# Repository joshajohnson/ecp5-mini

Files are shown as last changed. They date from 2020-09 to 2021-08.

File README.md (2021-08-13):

# ECP5 Mini

``` 
Status: All functions on r0.2 have been proven to work. Safe to assemble your own! 

Designed in Kicad nightly, ensure you clone --recursive.
```

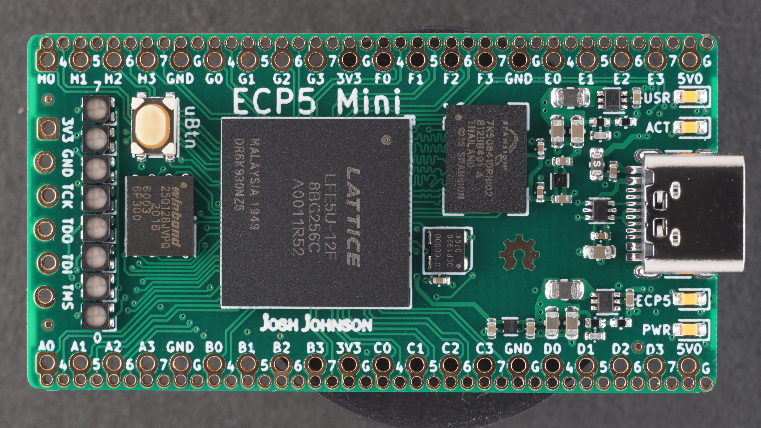
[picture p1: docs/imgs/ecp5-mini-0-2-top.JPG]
Top Side

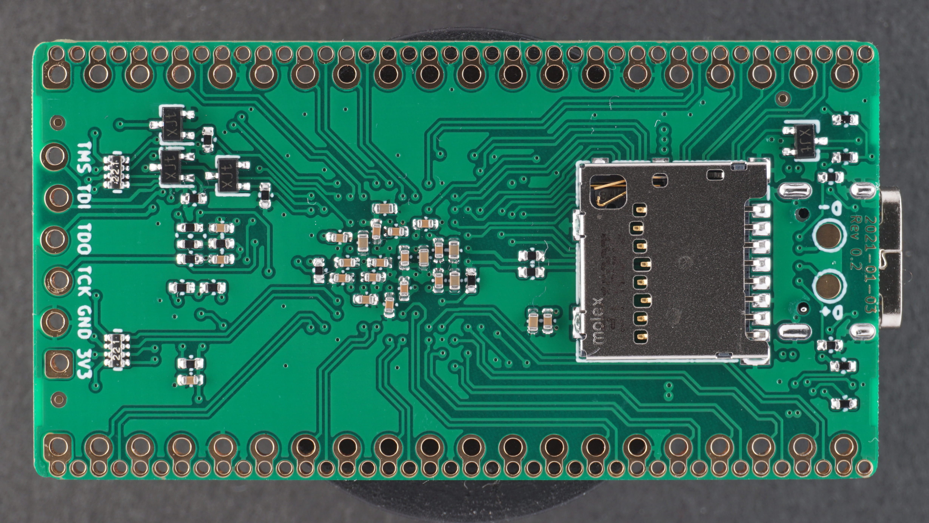
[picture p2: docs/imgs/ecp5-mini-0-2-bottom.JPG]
Bottom Side


ECP5 Mini is a Lattice ECP5 FPGA in the [Black Mesa Labs "S7 Mini" form factor](https://blackmesalabs.wordpress.com/2019/05/19/bml-s7-mini-fpga-module/).

## Key Features
- Lattice ECP5-12/25F FPGA in a caBGA256 package.
- 32 / 64 3V3 IO on 2.54mm / 1.27mm pitch grid.
- 64 Mbit HyperRAM DRAM.
- USB Full Speed (12Mbit) connection to FPGA over Type-C connector.
- MicroSD card support.
- 8 Multiplexed RGB LEDs.

## Revision History

r0.1 is depreciated. ~~hardware has been assembled with no major issues being found at time of writing. Requires more validation, particularly the HyperRAM, microSD, and signal integrity of IO.~~

r0.2 moves to 1v8 HyperRAM along with major IO changes to improve performance. Pinout is not compatiable with r0.1, but mechanically is identical. Projects utiliting the features of the board to be completed.

## Information

USB [dfu bootloader](https://github.com/joshajohnson/had2019-playground/tree/ecp5-mini) courtesy of [tnt](https://github.com/smunaut/) is working.

Example gateware can be found [here](https://github.com/joshajohnson/ecp5-mini-projects), however please note I built this board to force myself to write more HDL so it's probably full of bad practices.

Check the [issues](https://github.com/joshajohnson/ecp5-mini/issues) for any errata / improvements to the design.

## Thanks
Not only was this project inspired by the growing number of OSHW FPGA designs, but I referenced a number of them during the hardware development. A huge thank you needs to be given to these people as otherwise my design would likely have even more bugs...
- Black Mesa Lab's [S7 Mini](https://blackmesalabs.wordpress.com/2019/05/19/bml-s7-mini-fpga-module/) for the form factor and feature set inspiration.
- Greg Davil and his [OrangeCrab](https://github.com/gregdavill/OrangeCrab) and [Butterstick](https://github.com/gregdavill/butterstick) development boards. 
- Matt Venn's [Basic ECP5](https://github.com/mattvenn/basic-ecp5-pcb) design.
- SpriteTM / Hackaday's [2019 Supercon Badge](https://github.com/Spritetm/hadbadge2019_pcb).
- Luke Valenty's [TinyFPGA-EX](https://github.com/tinyfpga/TinyFPGA-EX).
- 1BitSquared's [HyperRAM PMOD](https://1bitsquared.com/collections/fpga/products/pmod-hyperram) for symbol and footprint.
- ECP5 Symbol from xesscorp's [Kicad Schematic Symbol Library](https://github.com/xesscorp/KiCad-Schematic-Symbol-Libraries).

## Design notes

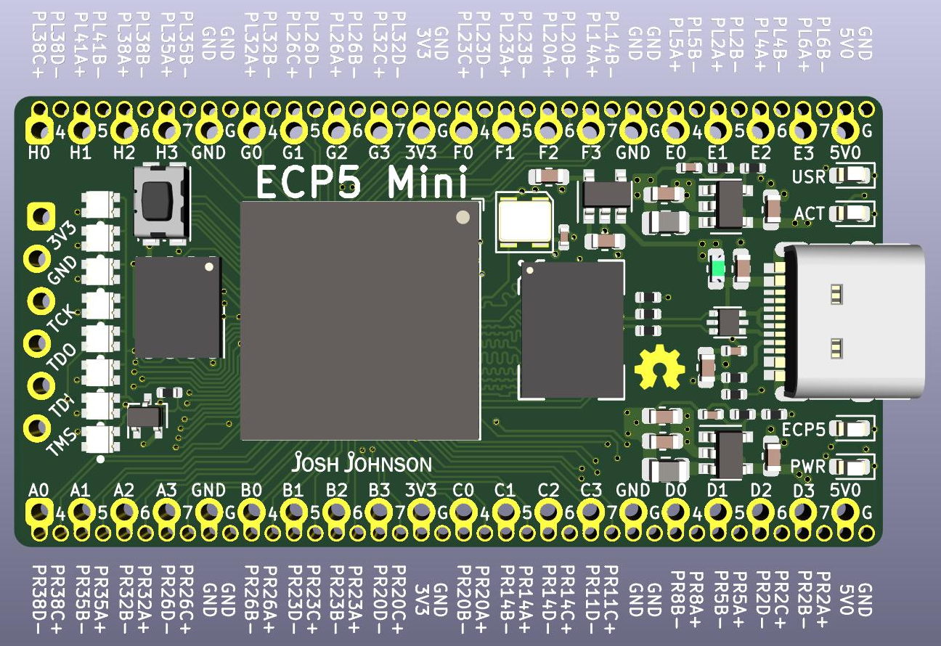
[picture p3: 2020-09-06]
docs/imgs/front-render.jpg

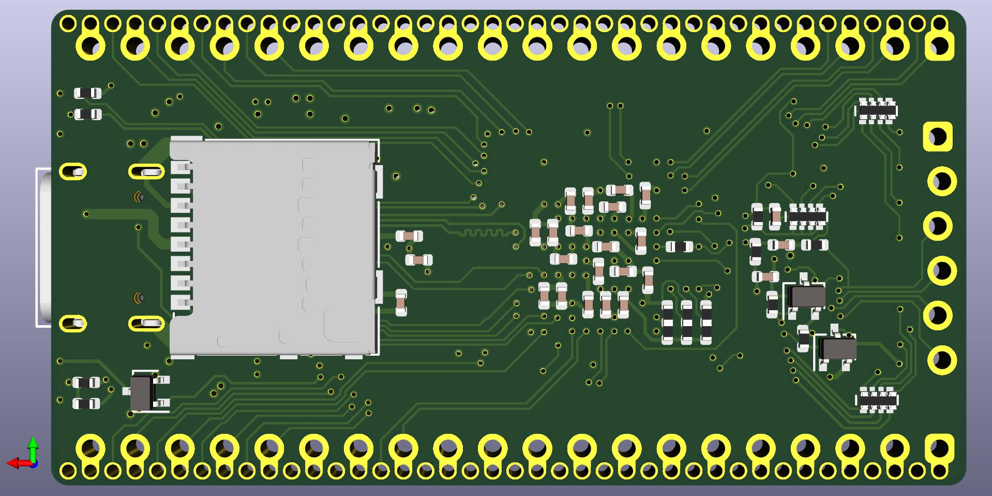
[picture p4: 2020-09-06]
docs/imgs/back-render.jpg

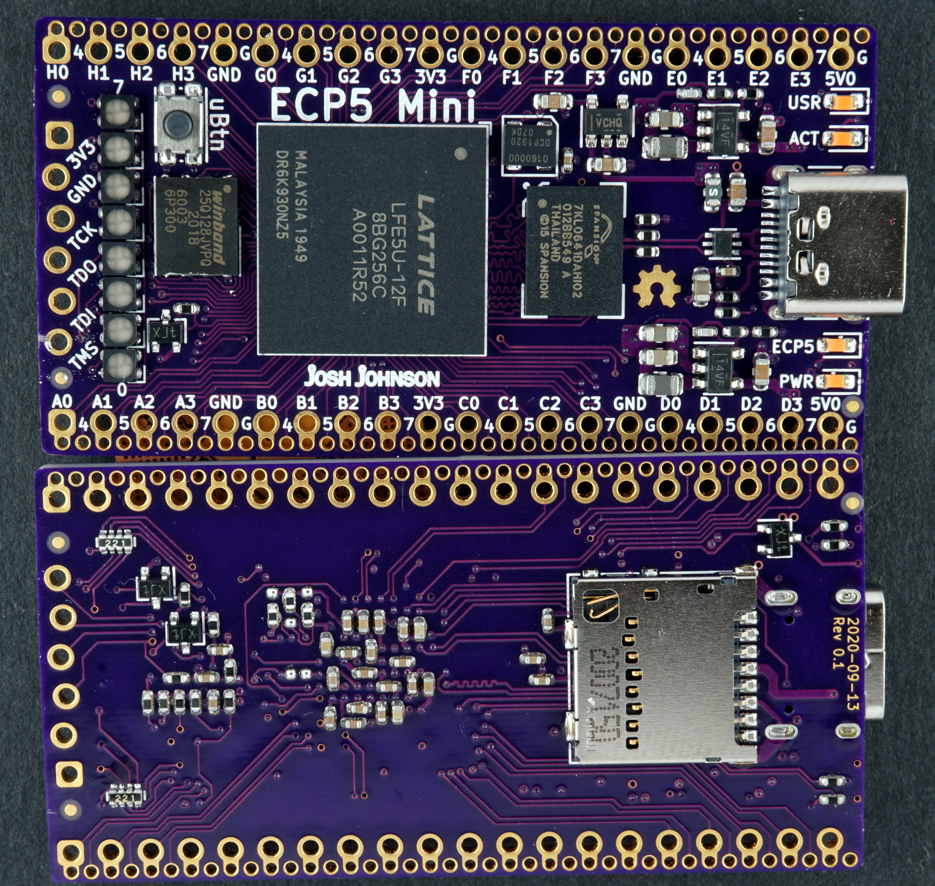
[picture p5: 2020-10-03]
docs/imgs/freshly-baked.jpeg

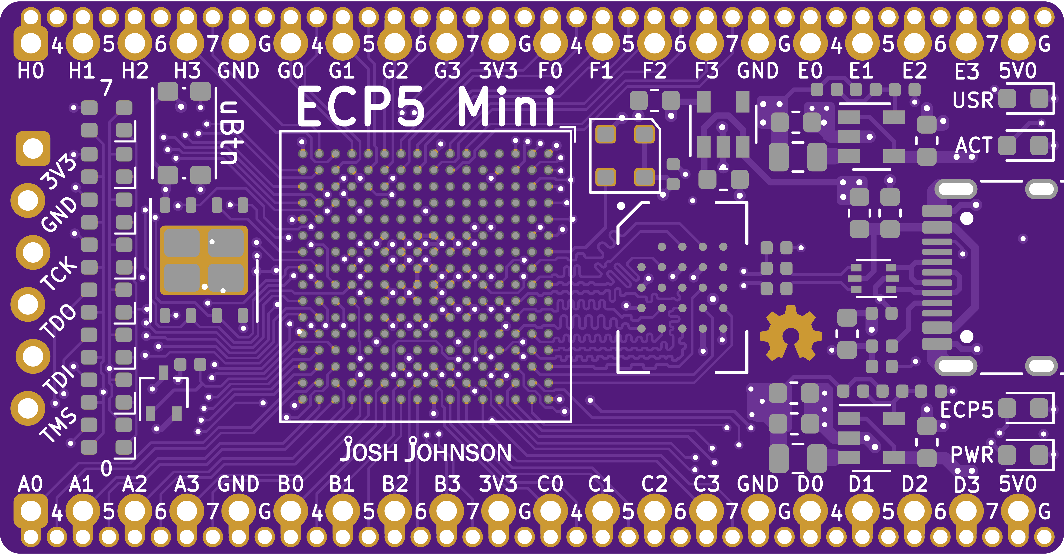
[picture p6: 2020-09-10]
docs/tracespace-render/top.png

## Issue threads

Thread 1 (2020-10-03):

r0.1 errata

joshajohnson, 2020-10-03:
This issue will document any errata / areas for improvement for future versions.

Note: HyperRAM and SD card are yet to be validated, issues list may grow once they are brought up.

Errata:
- [X] ECP5 ball T12 has a GND via partially occluding the pad
- [X] JTAG labels cannot be seen if header is installed
- [X] Diff pairs laid out uniquely, +/- is flipped compared other boards + uses C/D pair which lack differential pair drivers.
       0:4 (PMOD 1:7) = A:B etc is ideal, C:D okay as backup.

Improvements:
- [X] Move HyperRAM to 1v8 for increased speed, will require a dedicated bank / power supply
- [X] BOM optimisation / consolidation, particularly with caps and voltage feedback network
    - [X] Move usb_pu to bottom side with rest of 1k5 resistors
    - [X] 1v1 regulator appears to work fine with 2 x 10uF caps, does not require 22uF
    - [X] USB input cap can be commonised
    - [X] LED resistors to 1k5 - reduces BOM along with being a better brightness
    - [X] Standardise on 0402 components where possible
    - [X] Move DC:DC to smaller SOT package
    - [X] All LED drivers to bottom of board, confirm CDONE requires FET?
- [X] Move status LED vias away from the edge to aide with panelisation
- [X] Add USB pads under USB connector for easy flashing
- [X] Move as many vias up to 0.2/ 0.50mm as possible, or 0.2/0.45 under BGA
- [X] Change button as KMR2 is a bit hard to press

TODO:
- [ ] ~~Validate HyperRAM and SD card on r0.1 before ordering r0.2.~~
- [X] Update PMOD breakout to use ports B,C,F,G.
- [X] Update DFU bootloader with latest pinout.
- [X] Update .pcf and change makefile so examples work on both boards.

joshajohnson, 2020-12-09:
Expanding on the pinout errata, there are two main areas for improvement. Please not I'm not an ECP5 expert (far from it!) so there may be some inaccuracies in the below.

#### Diff pair pinout is not compatible with the de-facto PMOD standard.

The de-facto standard for diff pairs over a PMOD connector is +/- on 1/7, 2/8 etc. [example](https://raw.githubusercontent.com/gregdavill/advent-calendar-of-circuits-2020/main/icebreaker%2B%2B/production/icebreaker%2B%2B.pdf)
Ports A -> D on the  ECP5 Mini have the diff pairs the other way around, so may cause issues.
If you are designing the ECP5 Mini into a custom board, or using single ended IO, this is not a problem.

#### C/D Pairs are used for IO on Left and Right Sides

Per the lattice [IO Guide (pages 6, 10)](https://www.latticesemi.com/-/media/LatticeSemi/Documents/ApplicationNotes/EH/FPGA-TN-02032-1-3-ECP5-ECP5G-sysIO-Usage-Guide.ashx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), there are up to two sets of diff pairs per IO block on the left and right sides of the ECP5. The A/B pair contain true LVDS drivers, whereas the C/D pair do not. If possible we should break out A/B pairs instead of C/D pairs, as they have greater functionality. Note the top / bottom sides do not have LVDS drivers on any pins, so we should aim to have dedicated PMODs with the LVDS pairs run to them, leaving other PMODSs with the   lesser featured IO. If you are not taking advantage of the LVDS drivers, this is not a problem.

giggiu16, 2020-12-30:
Hi @joshajohnson!
When do you think the rev 0.2 will be finished? I really would like to try to assemble the board, as my first BGA assembly test 😃.

Thank you for your good work!

joshajohnson, 2020-12-31:
Hey @giggiu16!

I'm hoping to finish layout in the next day or two, but I won't have time to assemble / validate the changes / update the constraints file etc for a few months (I'm not guaranteeing anything before March - April, but I'll do my best to get around to it earlier).

In saying this, all of the IO changes are low risk as they are just changing the pinouts, and aside from the hyperram moving to 1v8 there were not too many changes to the core of the board, so should be fairly low risk.

I'll ping you here once it's done so you can kick off the assembly :)

giggiu16, 2020-12-31:
Thank you @joshajohnson and thank you again for your good work. I will try my best to assemble the r0.2 and test out the other untested things :)

joshajohnson, 2021-01-04:
Hey @giggiu16, 0.2 should be ready to order, files are in `hardware/0.2/outputs`. I've just ordered mine to fingers crossed they work...

Feel free to fire away with any questions / issues / PRs etc, interested to hear how you go!

Closed 2021-01-04.

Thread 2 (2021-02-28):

r0.2 Errata

joshajohnson, 2021-02-28:
This issue will document any errata / areas for improvement for future versions.

Note, whilst the board has passed the smoke test, it has not been fully brought up so this list is subject to growing.

- [ ] USB CC pulldown resistors are in the way of the SD card, card can still be inserted but is less than ideal.
- [ ] PD37+- diff pair is not routed correctly under the SD card.
- [ ] C510 is too close to C514
- [X] C14 and R2 should have their positions swapped in layout.

giggiu16, 2021-03-01:
Hey @joshajohnson! For a very big coincidence I assembled the r0.2 simultaneously with you! 😄
Just had the time to perform (a successful!) smoke test and an initial JTAG chain scan (w/ openocd& ftdi/jlink) but no devices were discovered. Do you managed to program the ECP5?
Thank you!

joshajohnson, 2021-03-01:
Hey @giggiu16, I was able to program both of the r0.2 boards I assembled. I used [ecpprog](https://github.com/gregdavill/ecpprog) with a FT232.

Let me know how you go / if there is anything I can do to help!

giggiu16, 2021-03-01:
@joshajohnson -- thank you so much!
Just changed to FT232 + ecpprog combination and...
```
init..
IDCODE: 0x21111043 (LFE5U-12)
ECP5 Status Register: 0x06400000
flash ID: 0xEF 0x40 0x18 0x00
Bye.
```

I confirm also that the bootloader is working correclty even on r0.2:
```
Found DFU: [1d50:614b] ver=0005, devnum=2, cfg=1, intf=0, path="20-4", alt=2, name="Bootloader", serial="e46050640f354126"
Found DFU: [1d50:614b] ver=0005, devnum=2, cfg=1, intf=0, path="20-4", alt=1, name="RISC-V firmware", serial="e46050640f354126"
Found DFU: [1d50:614b] ver=0005, devnum=2, cfg=1, intf=0, path="20-4", alt=0, name="ECP5 bitstream", serial="e46050640f354126"
```

Thank you so much!

joshajohnson, 2021-03-01:
@giggiu16 Nice work! If you are in the position to share what you are using it for I'd be keen to hear, otherwise have fun!

giggiu16, 2021-03-04:
@joshajohnson for sure: no specific use case in mind for now. I'll use your board to continue learning FPGA programming, I didn't wanted to be limitated in GPIO pins too much comparing other "low-cost" solutions. I like also assemblying electronic prototypes and I used your board as first BGA assembly test 😄. Next 2 boards in queue, and one is with the 25F variant 😉.

joshajohnson, 2021-03-05:
@giggiu16 Awesome!

One thing I should say is that the 12F and the 25F are the same silicon, but with a different IDCODEs. If you use the open tools you'll be able to use all 25K LUTs on the 12F!

amitvasudevan, 2022-09-28:
Hi @joshajohnson and @giggiu16! Nice work on the ECP5-mini board. How did you solder the BGA on the PCB? Did you just use a hot air gun/flux combo or was it something more sophisticated? Thanks!

joshajohnson, 2022-09-28:
Hi @amitvasudevan, I'd suggest reflowing it along with the rest of the components. You can do it with hot air but getting even heating is a bit more challenging.

joshajohnson, 2022-09-28:
Closed on accident

amitvasudevan, 2022-09-28:
Thanks for the response @joshajohnson !

I am a newbie when it comes down to soldering so please forgive my naive questions below :)

- From what I read up on reflow seems like a three step process: (a) obtain stencil for PCB, (b) apply solder paste over stencil, and (c) place the pcb in the reflow oven. Correct?
- I am planning to order the PCB via OSHPark; do they provide stencils?
- Also I noticed that your PCB design has components soldered on both the top and bottom. How does that work in the reflow oven? Do you do one side first and then the other? If so, won't the already soldered components on the side down reflow and dislodge?
- I am planning on assembling this at home and was looking for reflow ovens on amazon and it seems like there are units available for ~$250 or so. Is there a specific unit you would recommend? Also I am guessing the temperature will depend on the solder paste being used correct?

Thanks for your time and help! Can't wait to get started...

joshajohnson, 2022-09-29:
- Correct

- OSHStencils (no relation to OSHPark) provide stencils.

- Yes, you reflow the bottom side then the top side. There is no issues with the bottom side falling off on the second time through the oven as they are all lightweight.

- Esden has a good summary of modifying an oven [here[(https://forum.1bitsquared.com/t/upgrading-a-t962a-reflow-oven/126). I have a T962 (not T962A) and it's okay, but I'd buy the higher end option next time.

- Yes you will want to play around with a few boards / temperature profiles before throwing your first actual board in there to see what works best.

amitvasudevan, 2022-09-29:
Thanks @joshajohnson! This is very helpful. I looked at the T962/A modifications and found the thermocouple interface board is no longer available from 1bitsquared. Is that an important component or can I still work without it?

joshajohnson, 2022-09-30:
You can get away without it, I don't have one in my machine.
Just make sure you add the [cold junction compensation DS18B20](https://github.com/UnifiedEngineering/T-962-improvements/wiki/Dallas-18B20-for-cold-junction-mod) in the controller board to get a bit closer with the temperature.

amitvasudevan, 2022-09-30:
Got it! Would you be willing to share details on the solder paste you used and the corresponding T962 profile that worked for you? I am planning to use lead-free solder paste (just to be less toxic) and it seems like it could work with the SAC305 lead-free paste as described [here](https://www.youtube.com/watch?v=Hkl6rzhMPHY). Thanks again for your time and help!

joshajohnson, 2022-10-01:
I use leaded T4 paste so the profile won't be too useful.
Main thing to keep an eye out for is that any fast ramp rates will cause the oven to lag as it can't keep up with the fast changes in temperature, so pick a slow profile and run it a few times to see how the oven responds.

I've had my oven for 4 years now and as long as I put a part less than 80mm x 80mm in the center of the board it will solder without too many issues, but it took a while to get to that point.

amitvasudevan, 2022-10-04:
Thanks @joshajohnson! I have placed my order for the T962 and it should get here next week. Also, I found a lead-free solder paste with Tin/Bismuth alloy from Chipquik. If you look at the datasheet [here](http://www.chipquik.com/datasheets/SMDLTLFP.pdf), it seems to have a pretty smooth reflow curve (about 1C temp rise per second). Is that a slow enough profile for the oven you think?

joshajohnson, 2022-10-06:
Ah sorry I might not have been clear - you can use any solder paste but just need to make sure the ramp rate on your oven is slow.
Mine has two options - one shaped like a triangle and another that has a long soak profile before peaking, and I use the latter as it can't match the sharp profile.

Oscilllator, 2024-11-09:
Hi,

Did anyone manage to make use of the RAM on this board? I'm doing my first ECP5 board and am looking for designs to work from. RAM is a nice-to-have for my design so it would be good to have a known good implementation to work from.

joshajohnson, 2024-11-09:
Hi Dave,

Hyperram has been confirmed to work via a memtest in Litex.

Code is here:

https://github.com/joshajohnson/ecp5-mini-projects/tree/master/litex

Thanks

-------- Original Message --------
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

CCampbell71, 2024-12-14:
@joshajohnson I'm looking at assembling on! But the 25 vs 12... you mentioned the IDCODEZ is different, will I have issues flashing and using the dfu bootloader?

joshajohnson, 2024-12-17:
Hi @CCampbell71, you can fit whatever part you want. Just make sure this part of the makefile is correct for the IC.
https://github.com/joshajohnson/ecp5-mini-projects/blob/master/verilog/common.mk#L3

CCampbell71, 2025-01-04:
Thanks @joshajohnson! Ok so I got the pcb assembled, I used your design for the FPGA portion including usb, buttons, jtag, spi etc. exactly the same. I am now unable to connect via jtag. I tried ECPPROG and open fpga loader, and am using a TIGARD (Ftdi) cable. Verified all power banks are correct and DONE pin pulls low indicating it moved into initialization. But I cannot get it to recognize the fpga via jtag. Any recommendations for the first flash? It has not been configured before

joshajohnson, 2025-01-05:
It's been so long since I flashed an ECP5 I'm struggling to remember what it looks like @CCampbell71!

Assuming you are not getting any readback of an IDCODE at all?
All I can think of is a dodgy connection between Tigard (correct pins to each spot? tight fit in holes?) or bad soldering on the BGA.
Otherwise maybe it's a driver / udev issue? Can you try a different device and see if you can find that on JTAG?

Sorry for the non answer, let me know how you go.

CCampbell71, 2025-01-05:
Yes, I've triple checked all connections and used openfogaloader/ ecpprog and native diamond software. Still cannot get id code :/. Question: when you have a fresh brand new board that's never been configured, you simply power it up and connect JTAG? I do see behavior of the DONE pin led come on and then goes off indicating the FPGA moved on to the initialization phase. But doesn't configure (obviously) also tried straight up flashing the spi chip (Winbond) and I'm getting hit with the write protection stuff. Working through that with various software/programmers as well 😄

CCampbell71, 2025-01-05:
I did notice the hardware checklist callls for 4.kohm pullups on most of the jtag pins. I didn't do this but looks like you didn't either so I figured either was a non issue. TCK is pulled down via 10kohm

joshajohnson, 2025-01-06:
Yeah I think you just connect JTAG and send it, IIRC you should always be able to get the IDCODE irrespective of the device state.
Pin strapping sounds fine to me. Sorry for not being much use.

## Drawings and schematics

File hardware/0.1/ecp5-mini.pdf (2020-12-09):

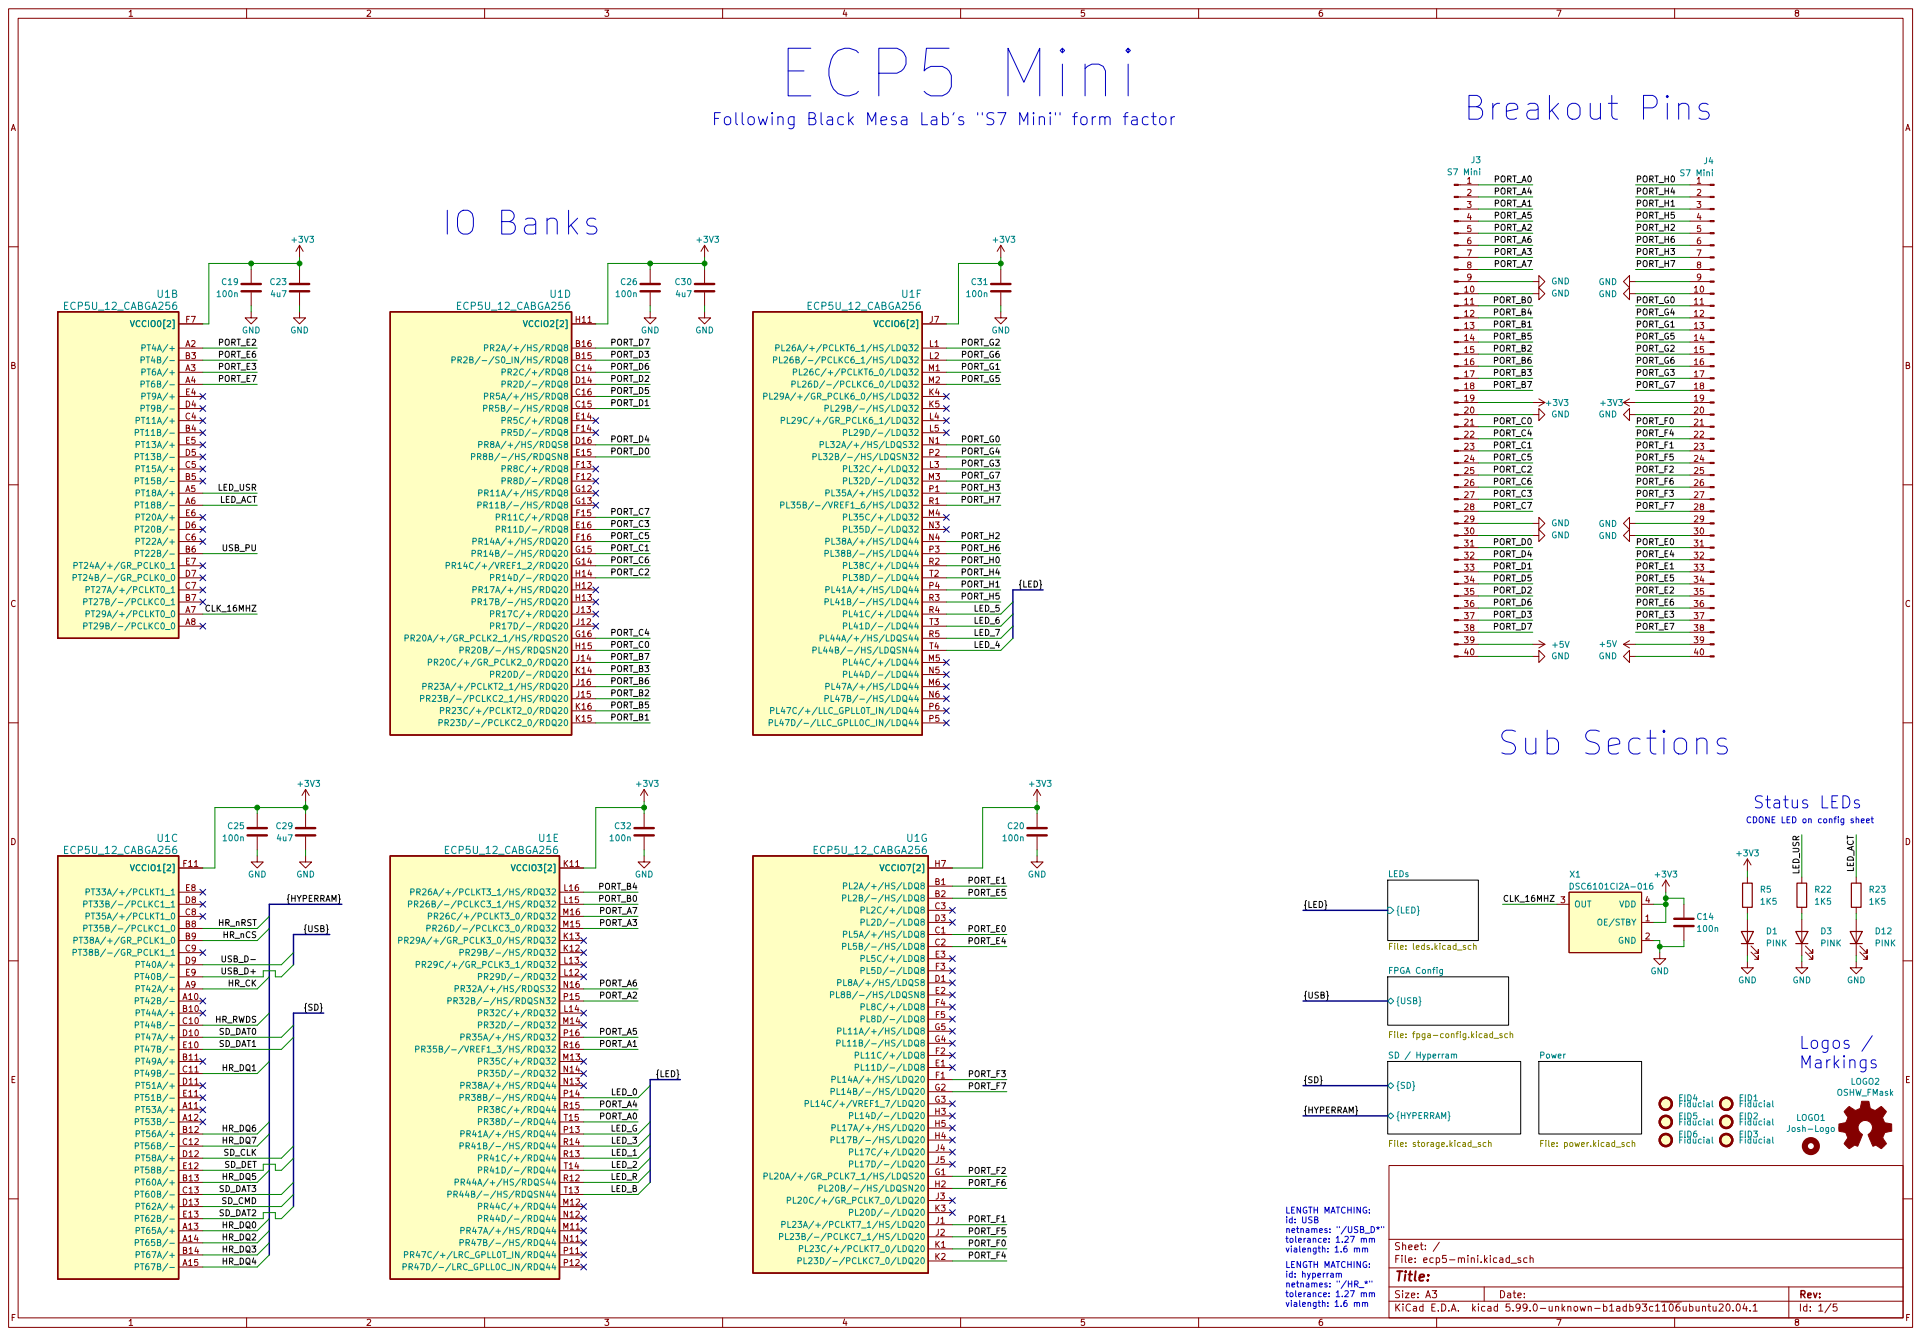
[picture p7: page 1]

Following Black Mesa Lab's "S7 Mini" form factor

Sub Sections
{HYPERRAM} LEDs File: leds.kicad_sch
{LED} LENGTH MATCHING:

CDONE LED on config sheet

File: fpga-config.kicad_sch
File: ecp5-mini.kicad_sch Sheet: / SD / Hyperram

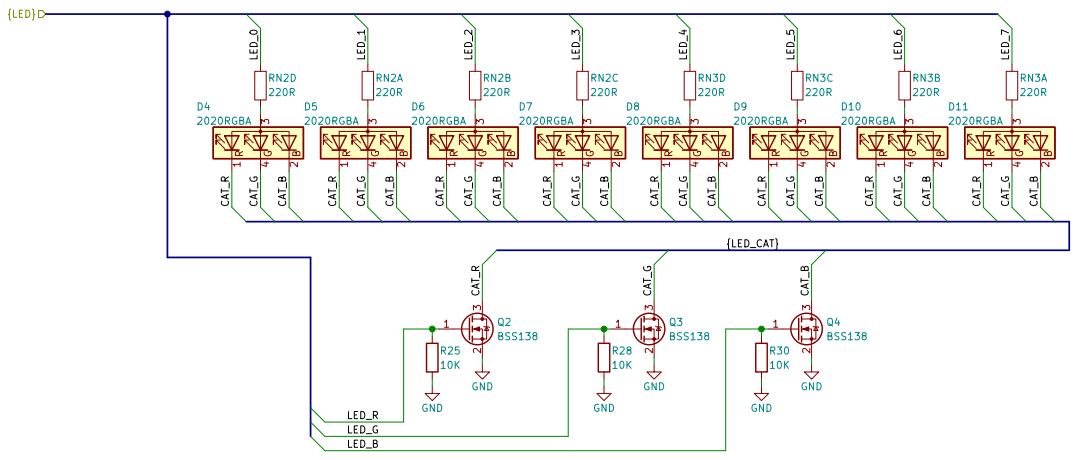
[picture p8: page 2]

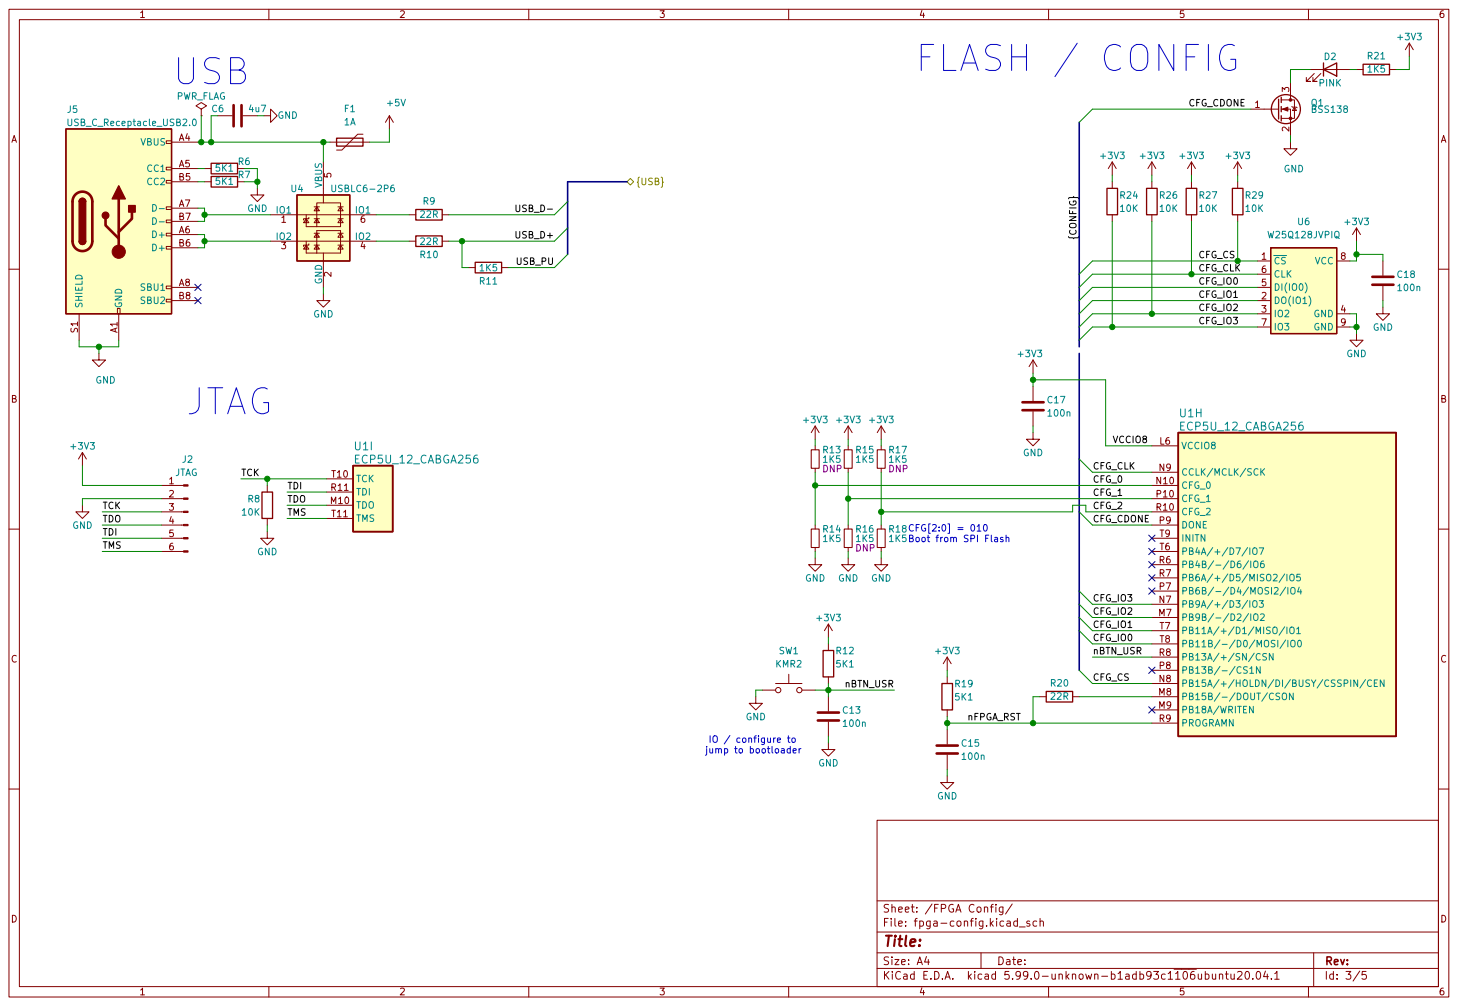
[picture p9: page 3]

CFG[2:0] = 010 Boot from SPI Flash

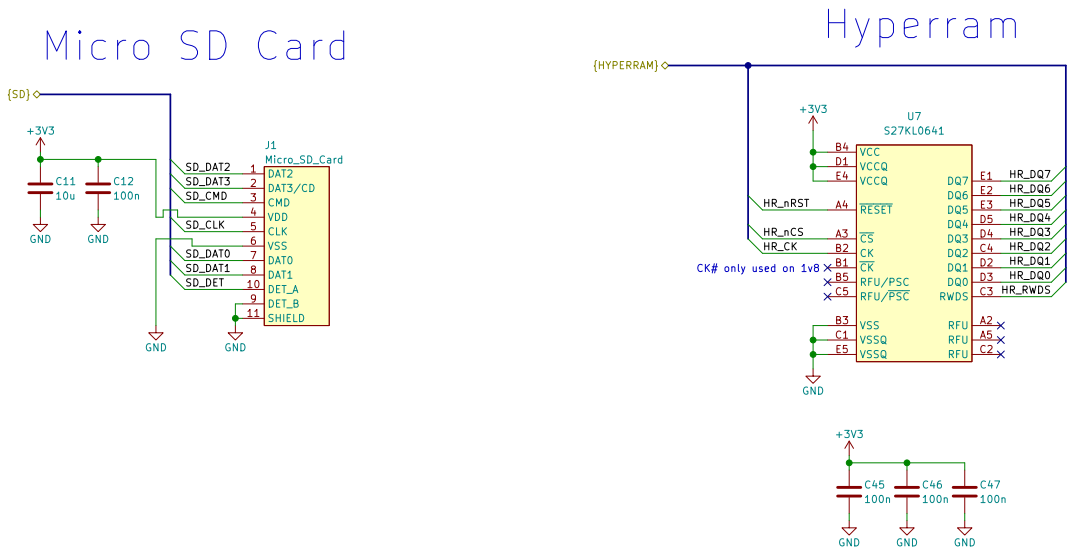
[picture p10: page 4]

CK# only used on 1v8

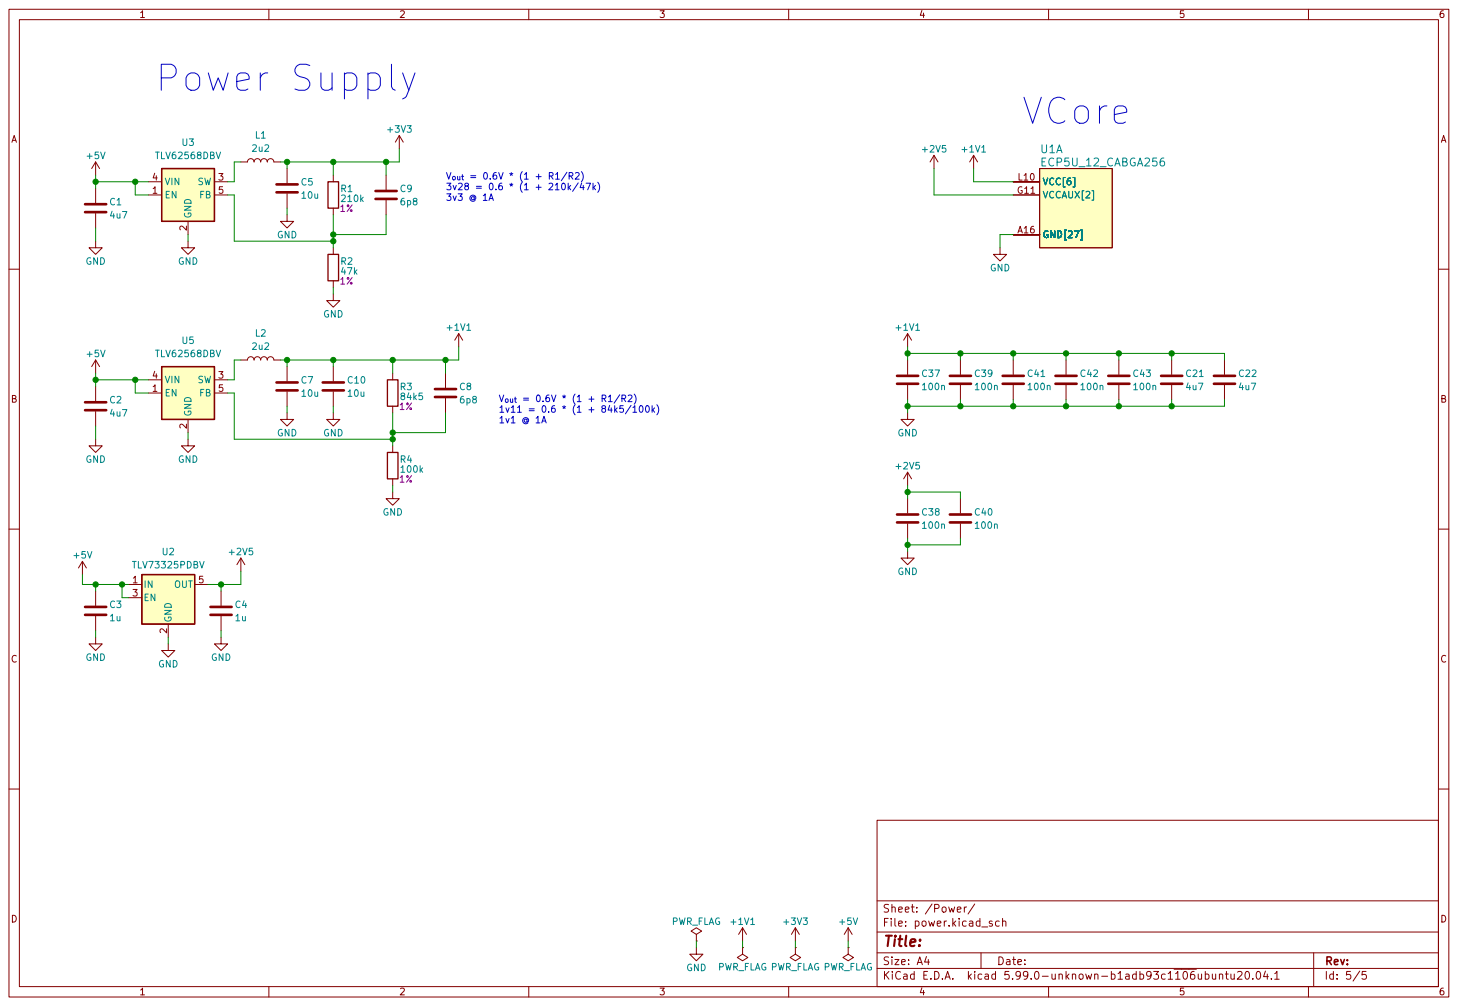
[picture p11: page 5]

File: power.kicad_sch Sheet: /Power/
Id: 5/5 Title:

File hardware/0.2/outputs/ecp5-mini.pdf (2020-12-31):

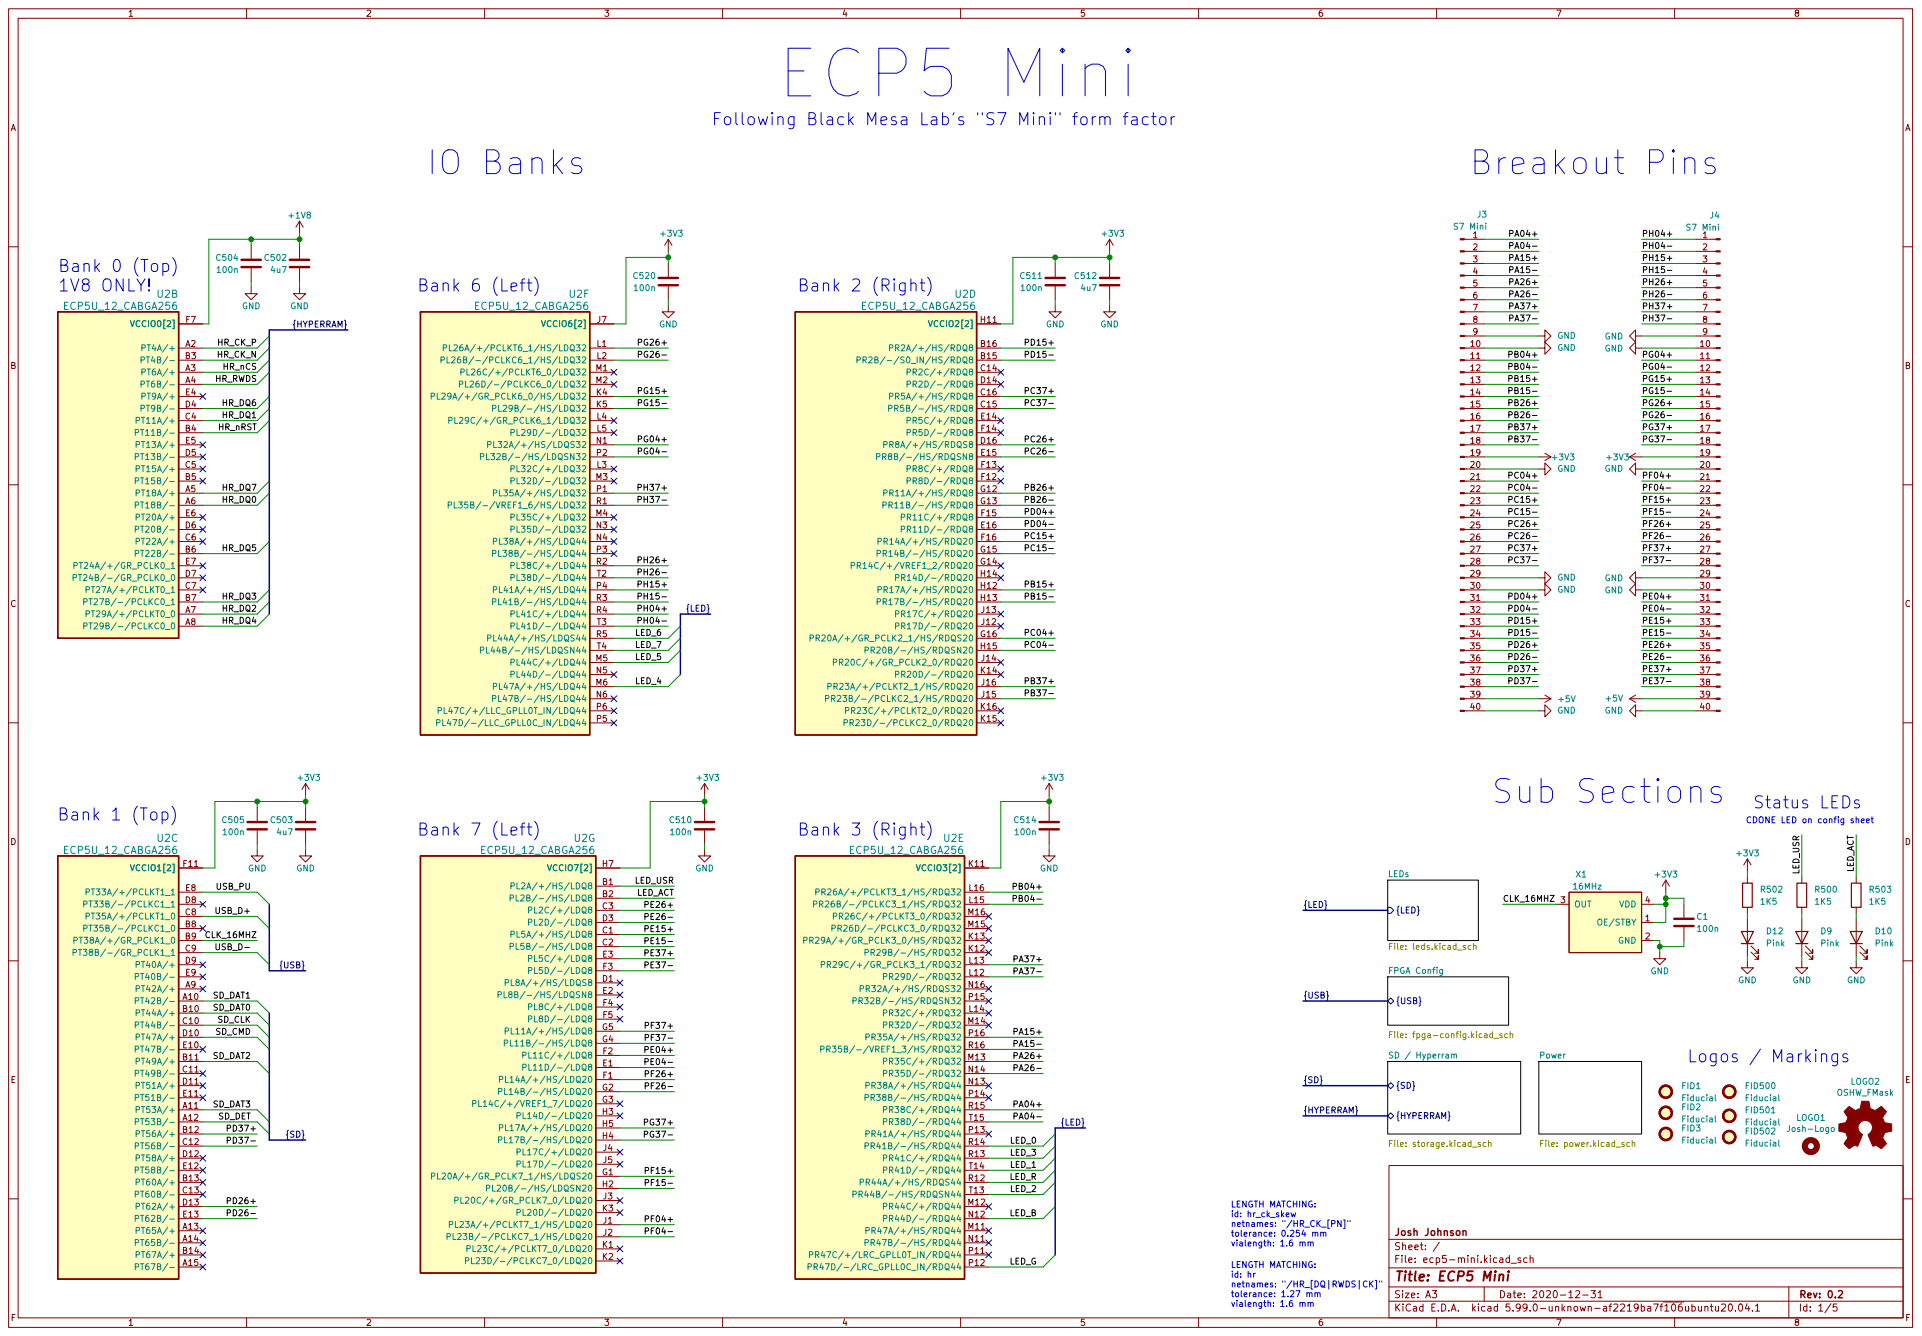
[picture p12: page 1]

Following Black Mesa Lab's "S7 Mini" form factor

D9Pink FID500 Fiducial FID502 Fiducial FID501 Fiducial FID2 Fiducial FID1 Fiducial FID3 Fiducial

File: ecp5-mini.kicad_sch Sheet: / Josh Johnson

LENGTH MATCHING:
id: hr netnames: "/HR_[DQ|RWDS|CK]"

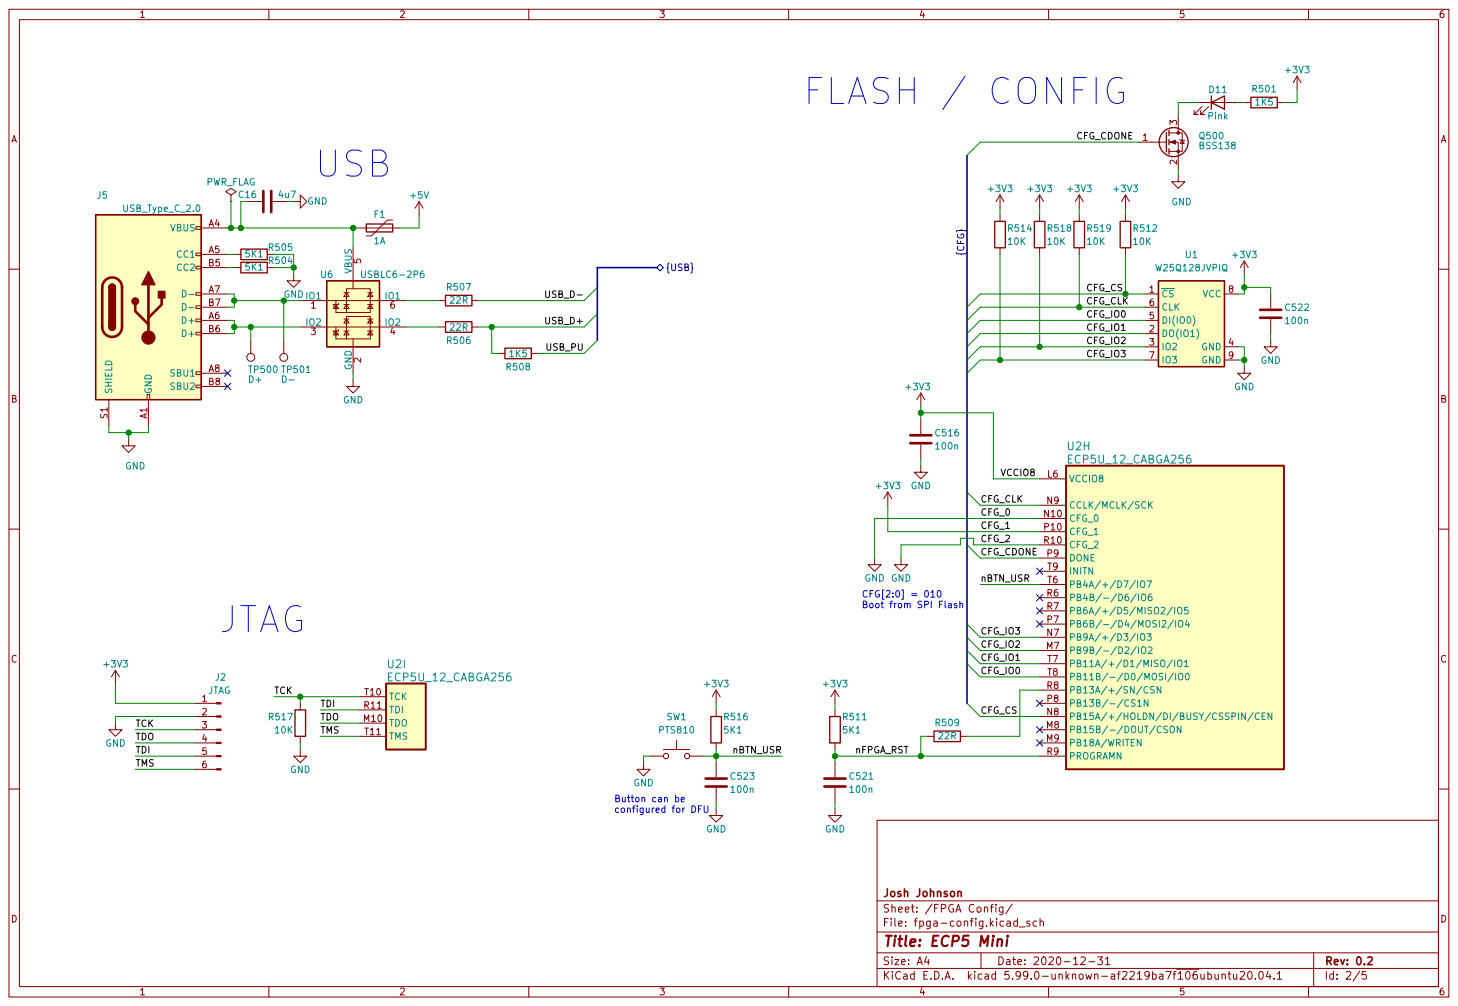
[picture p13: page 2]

Sheet: /FPGA Config/ Josh Johnson C521

Button can be configured for DFU

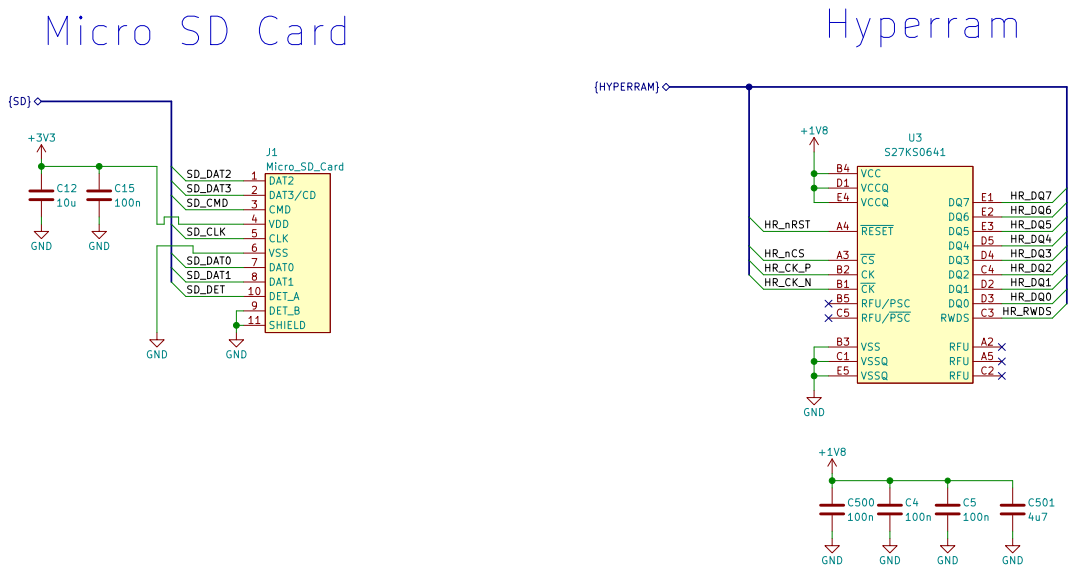
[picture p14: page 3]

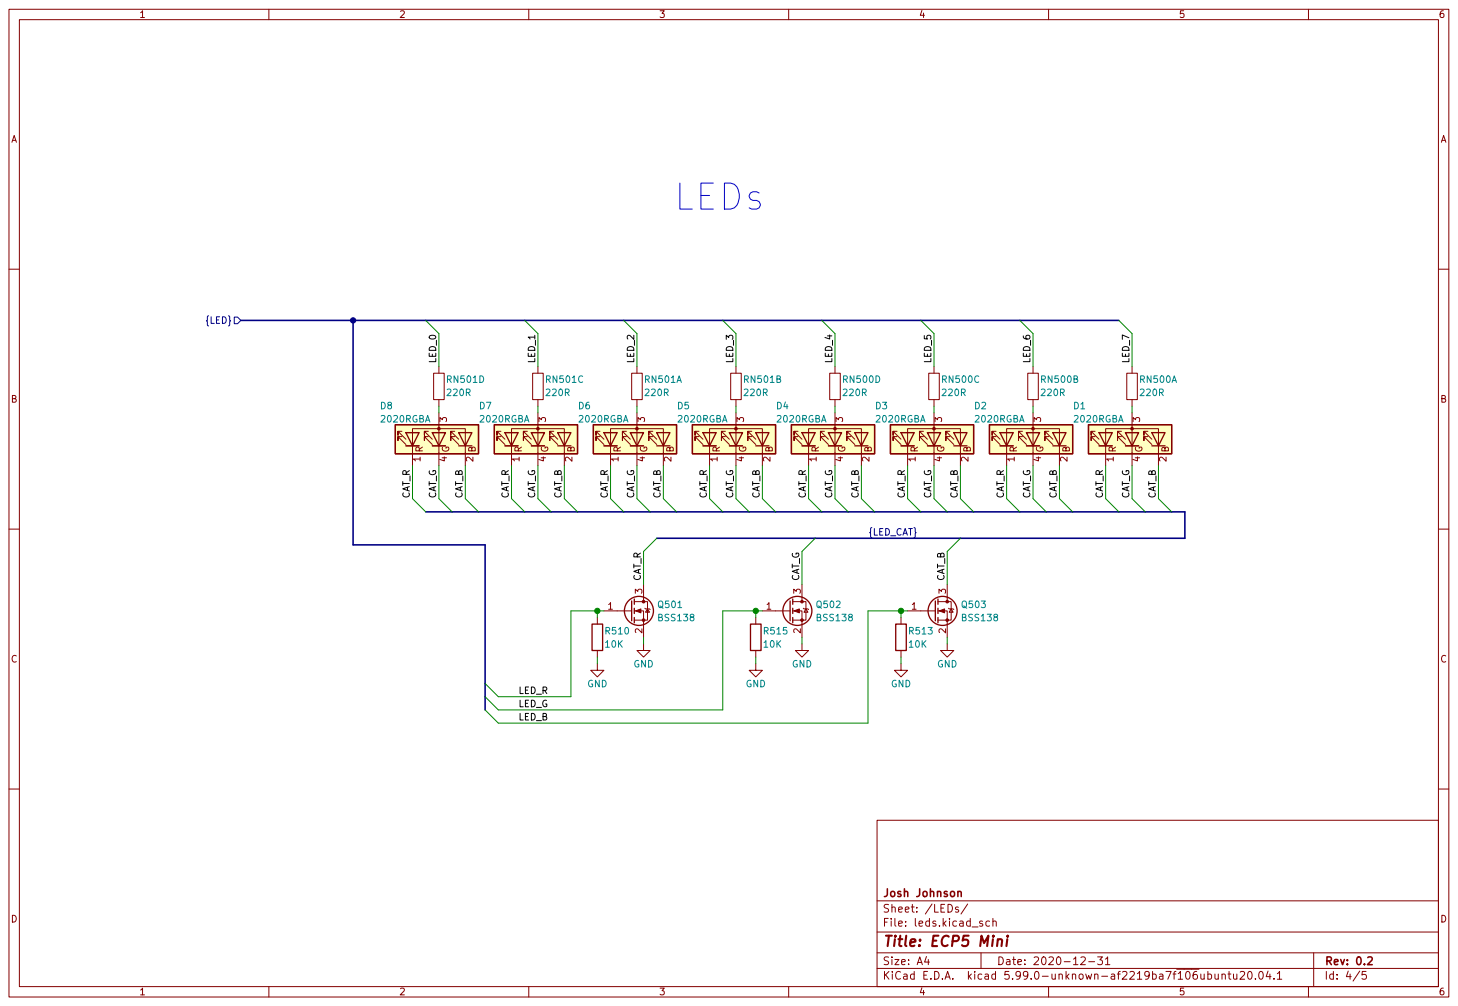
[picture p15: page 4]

File: leds.kicad_sch Sheet: /LEDs/ Josh Johnson

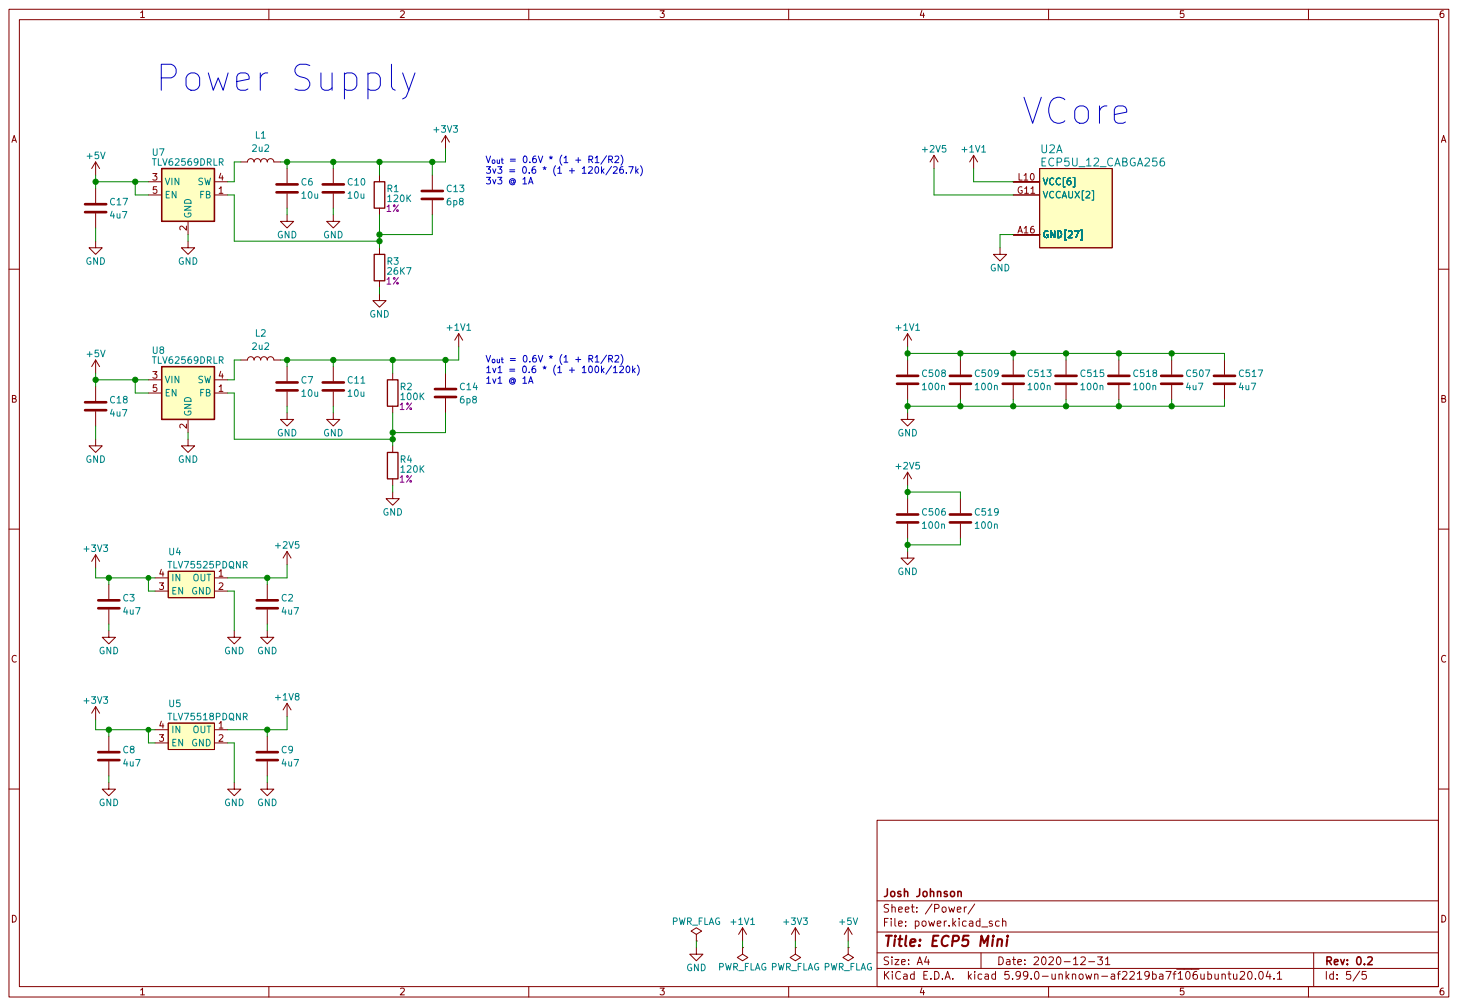
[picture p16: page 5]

2 VIN 3 SW 4 EN 5U7TLV62569DRLR GND

File: power.kicad_sch Sheet: /Power/ Josh Johnson

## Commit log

2020-08-21 set board outline
    [ecp5-mini.kicad_pcb, ecp5-mini.kicad_sch, ecp5-mini.sch]
2020-08-21 looks like it will fit
    [ecp5-io.kicad_sch, ecp5-mini.kicad_pcb, ecp5-mini.kicad_sch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]
2020-08-23 update gitignore
    [ecp5-mini.kicad_pcb, ecp5-mini.kicad_sch]
2020-08-27 power + leds + hyperram
    [board-io.kicad_sch, ecp5-mini.kicad_pcb, fpga-config.kicad_sch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]
2020-08-28 all 3d models added
    [board-io.kicad_sch, ecp5-mini.kicad_pcb, ecp5-mini.kicad_sch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]
2020-08-28 decoupling down + outer pins fanned out
    [ecp5-mini.kicad_pcb, ecp5-mini.kicad_sch, fpga-config.kicad_sch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]
2020-08-28 cleaning up schematic
    [board-io.kicad_sch, ecp5-io.kicad_sch, ecp5-mini.kicad_pcb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]
2020-08-29 layout ++
    [ecp5-mini.kicad_pcb, ecp5-mini.kicad_sch, fpga-config.kicad_sch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]
2020-08-29 hyperram routed
    [ecp5-mini.kicad_pcb, ecp5-mini.kicad_sch, fpga-config.kicad_sch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]
2020-08-29 half IO laid out
    [ecp5-mini.kicad_pcb, ecp5-mini.kicad_sch, fpga-config.kicad_sch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]
2020-08-30 half IO routed
    [ecp5-mini.kicad_pcb, ecp5-mini.kicad_sch, fpga-config.kicad_sch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]
2020-08-30 unrouted = 0
    [ecp5-mini.kicad_pcb, ecp5-mini.kicad_sch, fpga-config.kicad_sch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]
2020-08-30 clean up routing
    [ecp5-mini.kicad_pcb]
2020-09-01 all DRC / ERC errors signed off
    [ecp5-mini.kicad_pcb, ecp5-mini.kicad_sch, fpga-config.kicad_sch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]
2020-09-02 move sd connector
    [ecp5-mini.kicad_pcb, ecp5-mini.kicad_sch, fpga-config.kicad_sch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]
2020-09-02 clean up IO routing
    [ecp5-mini.kicad_pcb]
2020-09-05 adding silk
    [ecp5-mini.kicad_pcb, ecp5-mini.kicad_sch, fpga-config.kicad_sch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]
2020-09-07 change LEDs, optimise parts
    [ecp5-mini.kicad_pcb, ecp5-mini.kicad_sch, fpga-config.kicad_sch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]
2020-09-09 add part numbers
    [ecp5-mini.kicad_sch, fpga-config.kicad_sch, leds.kicad_sch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]
2020-09-10 design review done
    [ecp5-mini.kicad_pcb, ecp5-mini.kicad_sch, fpga-config.kicad_sch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]
2020-09-10 add fiducals
    [ecp5-mini.kicad_pcb, ecp5-mini.kicad_sch, fpga-config.kicad_sch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]
2020-09-13 set clearances to a more reasonable number
    [ecp5-mini.kicad_pcb, ecp5-mini.kicad_sch, fpga-config.kicad_sch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]
2020-09-20 quad pmod looks good
    [ecp5-mini.kicad_pcb, ecp5-mini.kicad_sch, fpga-config.kicad_sch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]
2020-09-20 add clock-test, rotate pmod legends
    [clock-test.kicad_pcb, clock-test.kicad_sch, clock-test.sch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]
2020-09-21 clock-test laid out
    [clock-test.kicad_pcb, clock-test.kicad_sch]
2020-09-21 octa pmod laid out
    [octa-pmod.kicad_pcb, octa-pmod.kicad_sch, octa-pmod.sch]
2020-09-21 octa horizontal laid out
    [octa-pmod.kicad_pcb, octa-pmod.kicad_sch, octa-pmod.sch]
2020-10-03 update readme following r0.1 bringup
    [clock-test.kicad_pcb, ecp5-mini.kicad_sch, fpga-config.kicad_sch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]
2020-10-05 update gateware examples + move breakout boards to own folder
    [clock-test.kicad_pcb, clock-test.kicad_sch, clock-test.sch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]
2020-10-19 update silk to clear connectors
    [octa-pmod.kicad_pcb, quad-pmod.kicad_pcb]
2020-12-09 update BOM
    [ecp5-mini.kicad_pcb, ecp5-mini.kicad_sch, fpga-config.kicad_sch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]
2020-12-09 revert layout to previous version
    [ecp5-mini.kicad_pcb]
2020-12-09 add .csv bom
    [ecp5-mini-bom.csv]
2020-12-27 0.2 layout begun
    [ecp5-mini-bom.csv, ecp5-mini.kicad_pcb, ecp5-mini.kicad_sch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]
2020-12-28 half IO routed out
    [ecp5-mini.kicad_pcb, ecp5-mini.kicad_sch, fpga-config.kicad_sch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]
2020-12-28 cleaned up diff pairs + routed power
    [ecp5-mini.kicad_pcb, ecp5-mini.kicad_sch, fpga-config.kicad_sch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]
2020-12-30 hyperram now length matched
    [ecp5-mini.kicad_pcb, ecp5-mini.kicad_sch, fpga-config.kicad_sch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]
2020-12-31 almost there
    [ecp5-mini.kicad_pcb, ecp5-mini.kicad_sch, fpga-config.kicad_sch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]
2020-12-31 version breakouts in advance of r0.2 pinout changes
    [clock-test.kicad_pcb, clock-test.kicad_sch, clock-test.sch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]
2020-12-31 shipped 0.2
    [ecp5-mini.kicad_pcb, ecp5-mini.kicad_sch, ecp5-mini.sch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]
2021-01-03 checking for the final time
    [ecp5-mini.kicad_sch, fpga-config.kicad_sch, leds.kicad_sch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]
2021-01-03 final check over breakouts
    [octa-pmod.kicad_pcb, octa-pmod.kicad_sch, quad-pmod.kicad_pcb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]
2021-01-03 release v0.2 for real this time
    [ecp5-mini.kicad_pcb]
2021-01-04 bom fix
    [ecp5-mini.kicad_sch, fpga-config.kicad_sch, leds.kicad_sch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]
2021-02-28 post 0.2 assembly updates
    [ecp5-mini.kicad_pcb, ecp5-mini.kicad_sch, fpga-config.kicad_sch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]
2021-04-17 add UNTESTED footprints
2021-04-17 nightly version bump
    [ecp5-mini.kicad_pcb, ecp5-mini.kicad_sch, fpga-config.kicad_sch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]
2021-08-13 bump kicad lib
